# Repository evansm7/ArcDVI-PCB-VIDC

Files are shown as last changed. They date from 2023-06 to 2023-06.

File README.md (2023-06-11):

# ArcDVI VIDC push-on PCB

Kicad 6.0 PCB design for the ArcDVI soldered-VIDC push-on board:

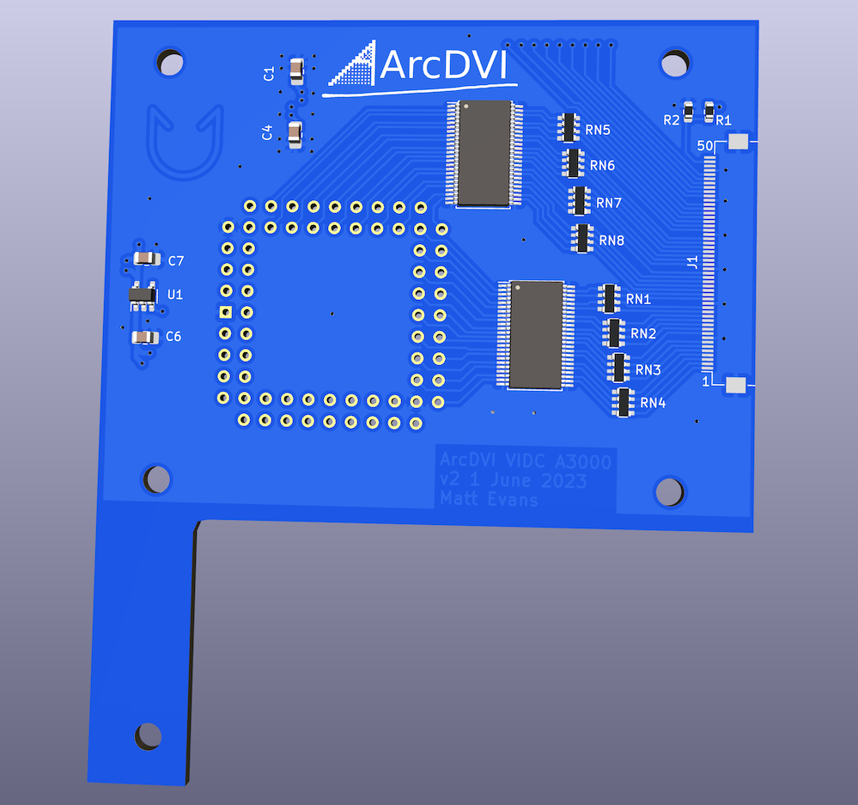
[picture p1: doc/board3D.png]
3D board


This board carries an upturned PTH PLCC68 which plugs onto a soldered VIDC from above.  This should fit an Acorn A3000, but hasn't been mechanically tested with the other soldered-VIDC machine, A5000.  The board exports the buffered signals over FFC to the ArcDVI main PCB.  Mechanically, the main PCB is designed to bolt on top of this board (with appropriate spacers) and fit underneath the floppy drive.

See <https://stardot.org.uk> for more info.

# License

ArcDVI is copyright 2023 Matt Evans.

This work is licensed under the Creative Commons Attribution-NonCommercial-ShareAlike 3.0 Unported License. To view a copy of this license, visit http://creativecommons.org/licenses/by-nc-sa/3.0/ or send a letter to Creative Commons, PO Box 1866, Mountain View, CA 94042, USA.

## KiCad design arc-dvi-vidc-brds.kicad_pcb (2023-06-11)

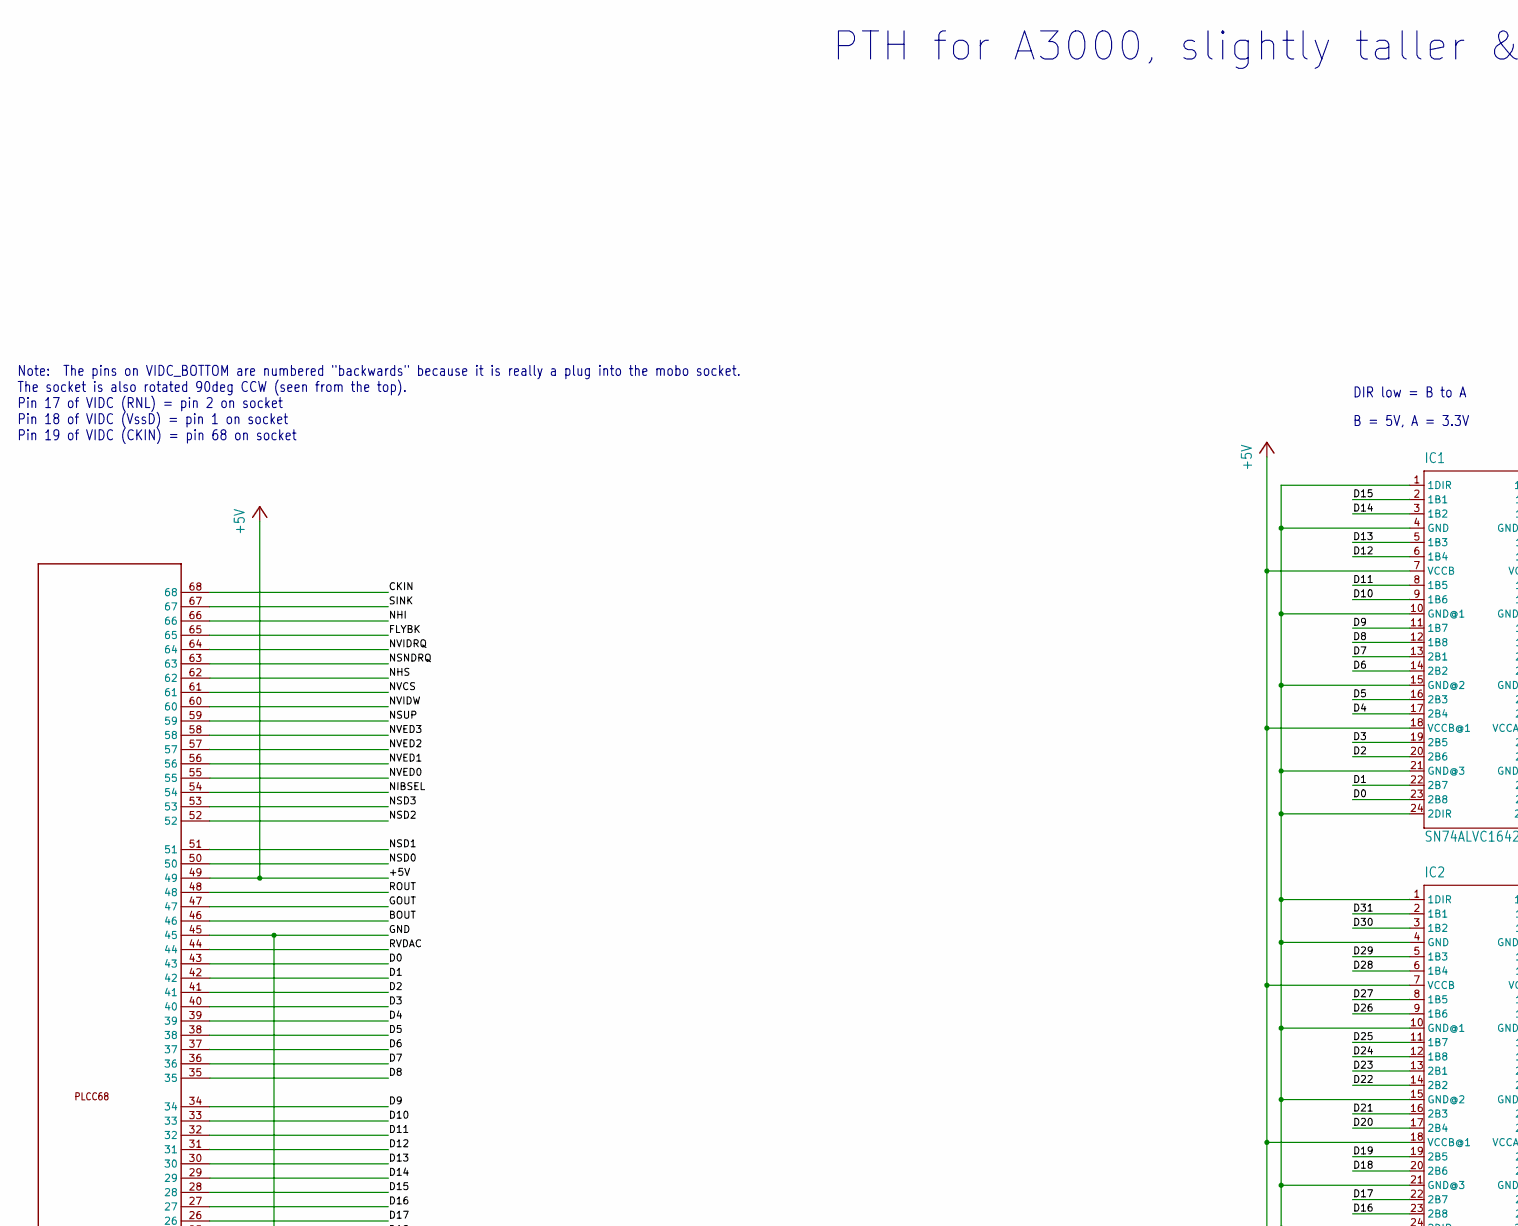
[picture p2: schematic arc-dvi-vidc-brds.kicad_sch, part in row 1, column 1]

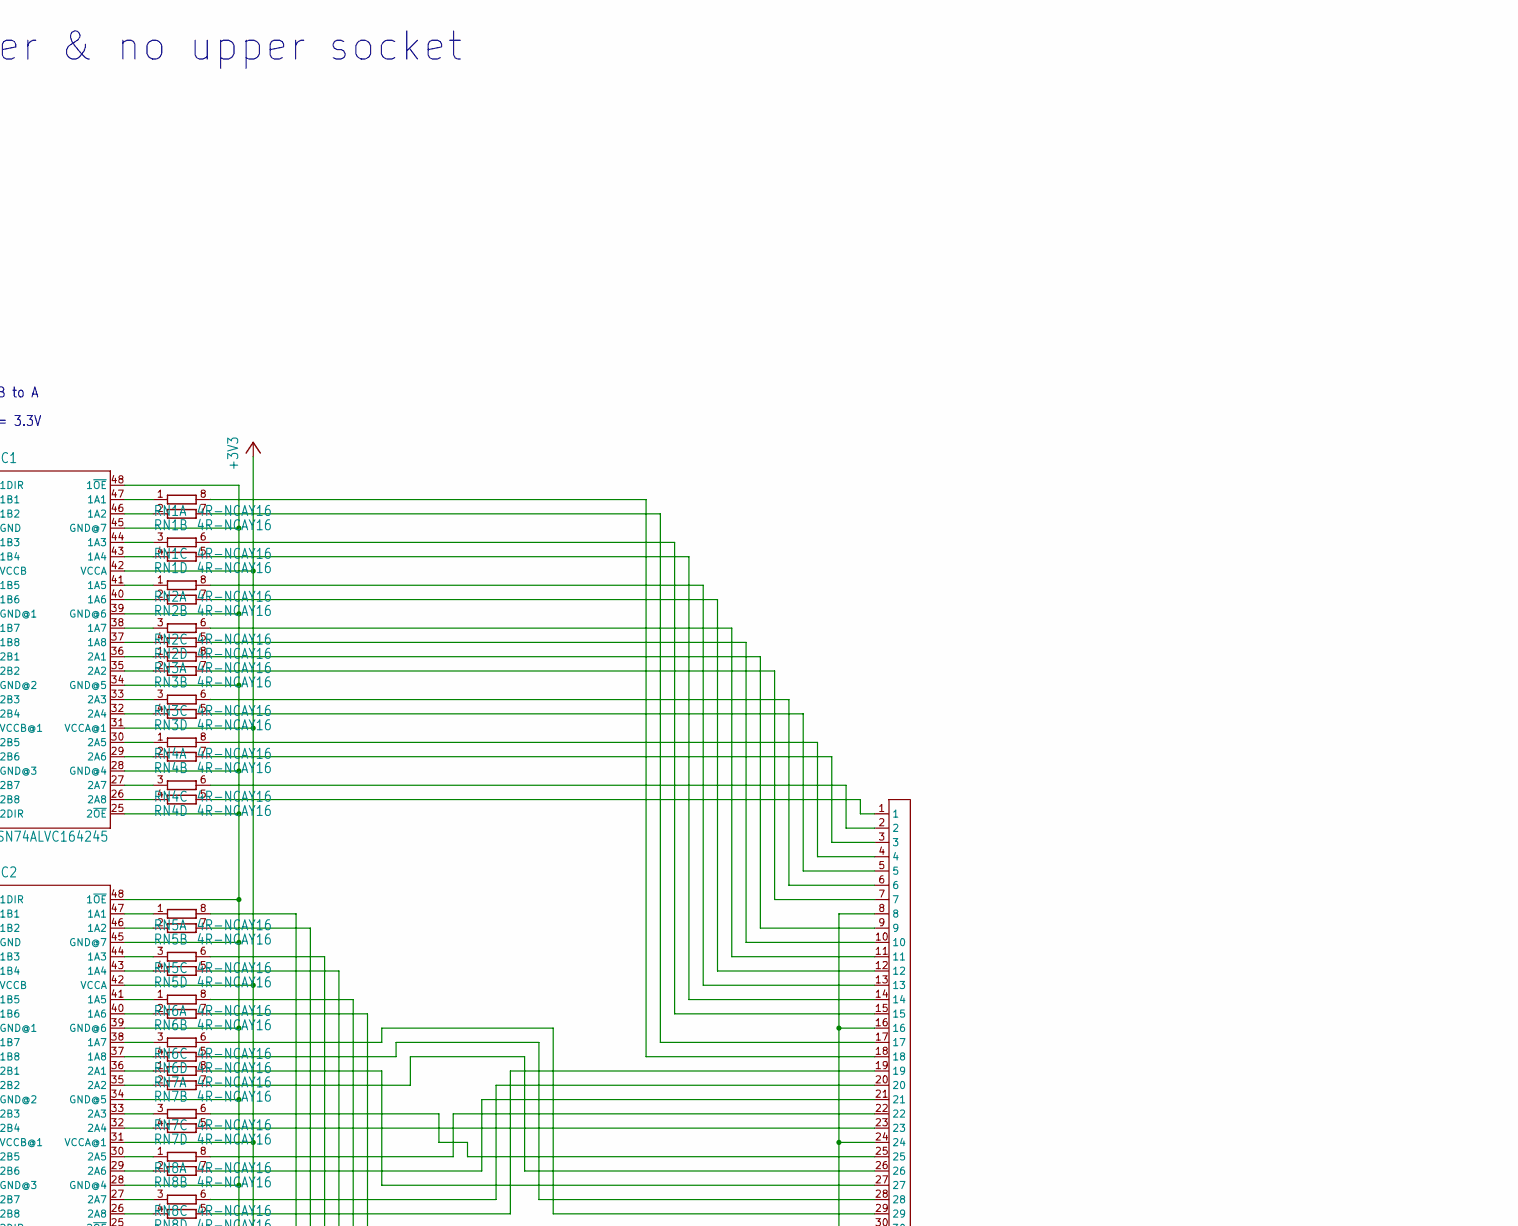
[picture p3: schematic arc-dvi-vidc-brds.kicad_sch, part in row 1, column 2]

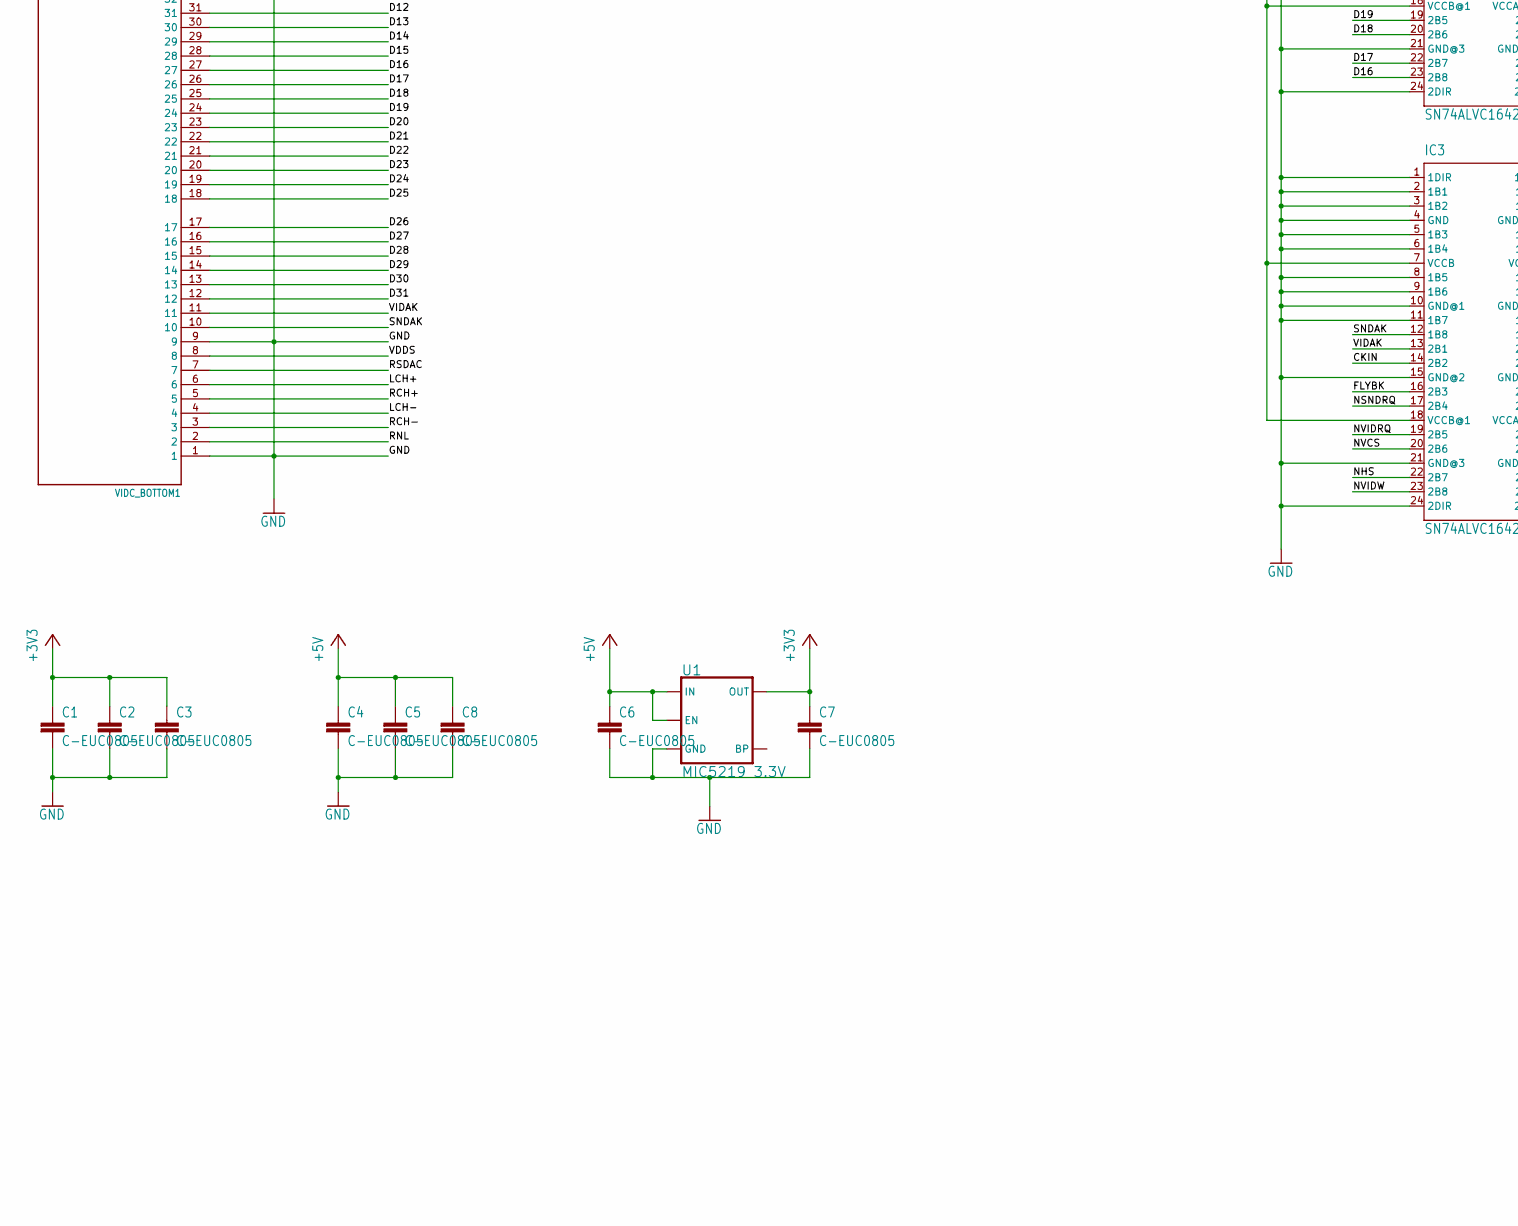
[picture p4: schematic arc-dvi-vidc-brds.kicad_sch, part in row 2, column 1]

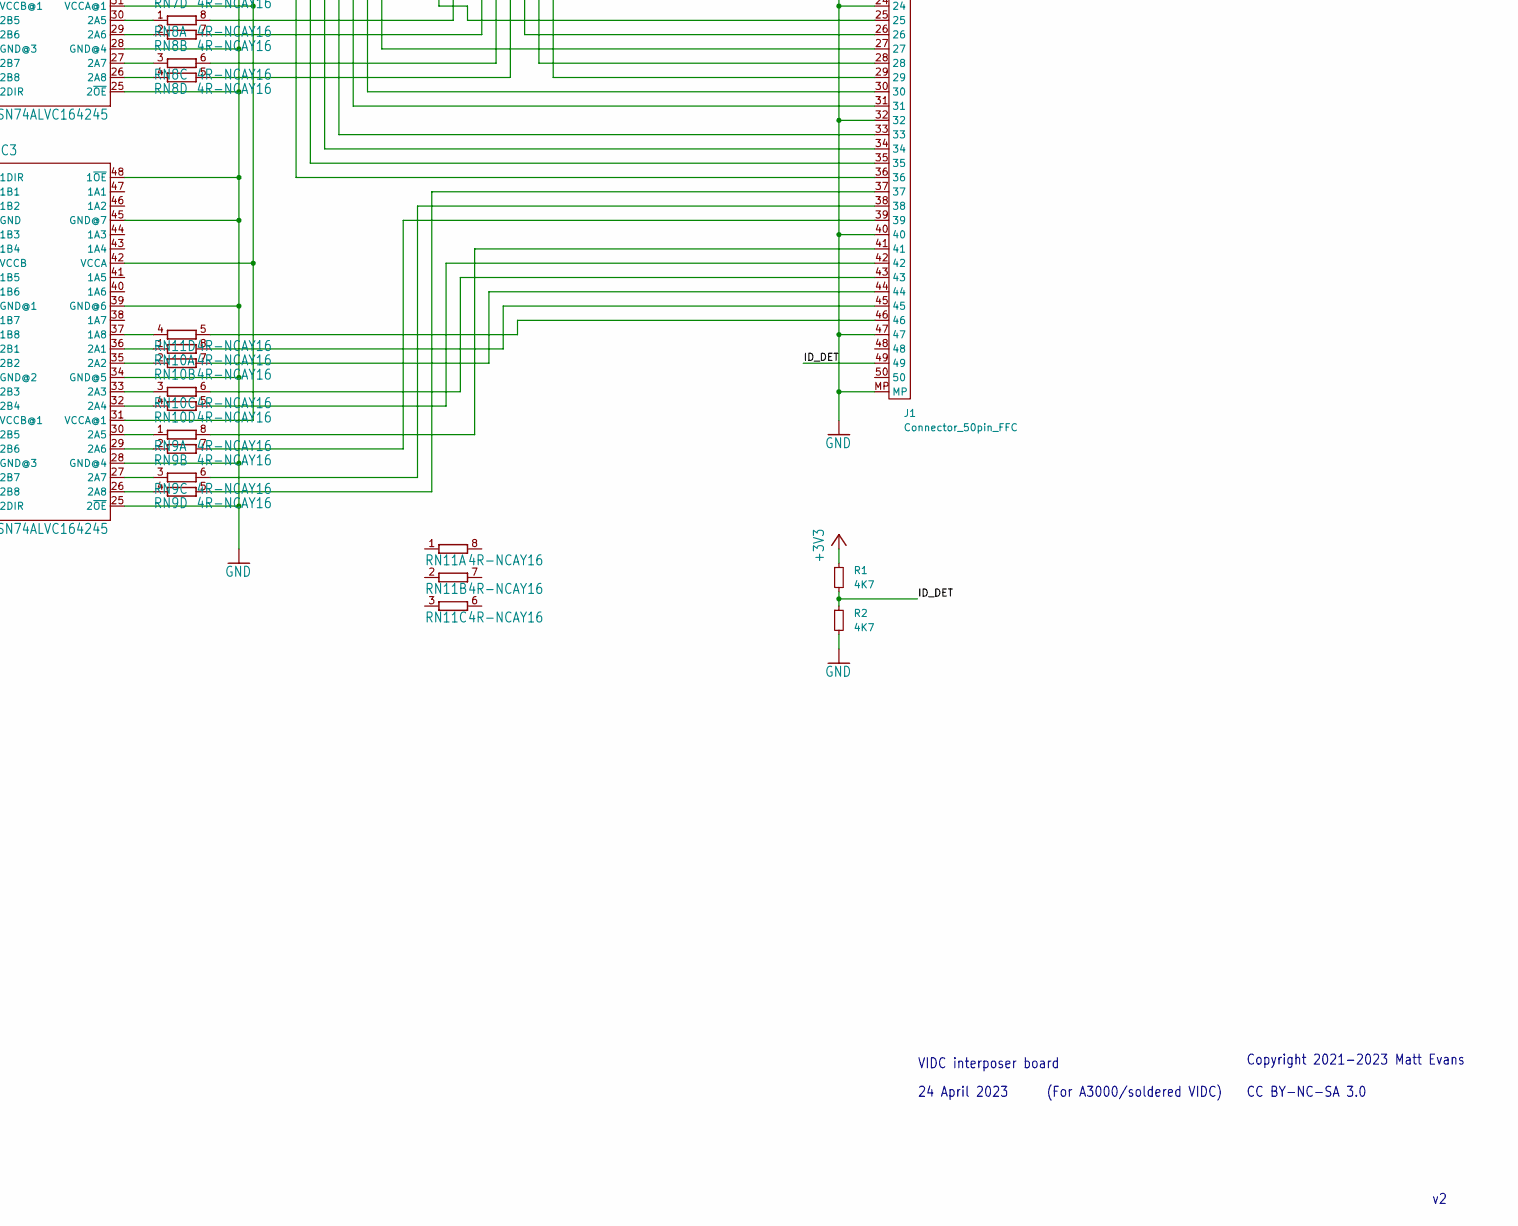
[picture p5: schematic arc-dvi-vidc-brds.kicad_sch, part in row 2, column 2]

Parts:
C1, C2, C3, C4, C5, C6, C7, C8: C-EUC0805; C_0805_2012Metric_Pad1.18x1.45mm_HandSolder
IC1, IC2, IC3: SN74ALVC164245; TSSOP-48_6.1x12.5mm_P0.5mm
J1: Connector_50pin_FFC; Hirose_FH12-50S-0.5SH_1x50-1MP_P0.50mm_Horizontal
R1, R2: 4K7; R_0603_1608Metric
RN1, RN2, RN3, RN4, RN5, RN6, RN7, RN8, RN9, RN10, RN11: 4R-NCAY16; R_Array_Convex_4x0603
U1: MIC5219 3.3V; SOT-23-5
VIDC_BOTTOM1: RAW_PLCC68PTH; PLCC-68_THT-Socket

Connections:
+3V3: C1.1, C2.1, C3.1, C7.1, IC1.31 (VCCA@1), IC1.42 (VCCA), IC2.31 (VCCA@1), IC2.42 (VCCA), IC3.31 (VCCA@1), IC3.42 (VCCA), R1.1, U1.5 (OUT)
+5V: C4.1, C5.1, C6.1, C8.1, IC1.7 (VCCB), IC1.18 (VCCB@1), IC2.7 (VCCB), IC2.18 (VCCB@1), IC3.7 (VCCB), IC3.18 (VCCB@1), U1.1 (IN), U1.3 (EN), VIDC_BOTTOM1.49
/BOUT: VIDC_BOTTOM1.46
/CKIN: IC3.14 (2B2), VIDC_BOTTOM1.68
/D0: IC1.23 (2B8), VIDC_BOTTOM1.43
/D1: IC1.22 (2B7), VIDC_BOTTOM1.42
/D2: IC1.20 (2B6), VIDC_BOTTOM1.41
/D3: IC1.19 (2B5), VIDC_BOTTOM1.40
/D4: IC1.17 (2B4), VIDC_BOTTOM1.39
/D5: IC1.16 (2B3), VIDC_BOTTOM1.38
/D6: IC1.14 (2B2), VIDC_BOTTOM1.37
/D7: IC1.13 (2B1), VIDC_BOTTOM1.36
/D8: IC1.12 (1B8), VIDC_BOTTOM1.35
/D9: IC1.11 (1B7), VIDC_BOTTOM1.34
/D10: IC1.9 (1B6), VIDC_BOTTOM1.33
/D11: IC1.8 (1B5), VIDC_BOTTOM1.32
/D12: IC1.6 (1B4), VIDC_BOTTOM1.31
/D13: IC1.5 (1B3), VIDC_BOTTOM1.30
/D14: IC1.3 (1B2), VIDC_BOTTOM1.29
/D15: IC1.2 (1B1), VIDC_BOTTOM1.28
/D16: IC2.23 (2B8), VIDC_BOTTOM1.27
/D17: IC2.22 (2B7), VIDC_BOTTOM1.26
/D18: IC2.20 (2B6), VIDC_BOTTOM1.25
/D19: IC2.19 (2B5), VIDC_BOTTOM1.24
/D20: IC2.17 (2B4), VIDC_BOTTOM1.23
/D21: IC2.16 (2B3), VIDC_BOTTOM1.22
/D22: IC2.14 (2B2), VIDC_BOTTOM1.21
/D23: IC2.13 (2B1), VIDC_BOTTOM1.20
/D24: IC2.12 (1B8), VIDC_BOTTOM1.19
/D25: IC2.11 (1B7), VIDC_BOTTOM1.18
/D26: IC2.9 (1B6), VIDC_BOTTOM1.17
/D27: IC2.8 (1B5), VIDC_BOTTOM1.16
/D28: IC2.6 (1B4), VIDC_BOTTOM1.15
/D29: IC2.5 (1B3), VIDC_BOTTOM1.14
/D30: IC2.3 (1B2), VIDC_BOTTOM1.13
/D31: IC2.2 (1B1), VIDC_BOTTOM1.12
/FLYBK: IC3.16 (2B3), VIDC_BOTTOM1.65
/GOUT: VIDC_BOTTOM1.47
/ID_DET: J1.49, R1.2, R2.1
/LCH+: VIDC_BOTTOM1.6
/LCH-: VIDC_BOTTOM1.4
/NHI: VIDC_BOTTOM1.66
/NHS: IC3.22 (2B7), VIDC_BOTTOM1.62
/NIBSEL: VIDC_BOTTOM1.54
/NSD0: VIDC_BOTTOM1.50
/NSD1: VIDC_BOTTOM1.51
/NSD2: VIDC_BOTTOM1.52
/NSD3: VIDC_BOTTOM1.53
/NSNDRQ: IC3.17 (2B4), VIDC_BOTTOM1.63
/NSUP: VIDC_BOTTOM1.59
/NVCS: IC3.20 (2B6), VIDC_BOTTOM1.61
/NVED0: VIDC_BOTTOM1.55
/NVED1: VIDC_BOTTOM1.56
/NVED2: VIDC_BOTTOM1.57
/NVED3: VIDC_BOTTOM1.58
/NVIDRQ: IC3.19 (2B5), VIDC_BOTTOM1.64
/NVIDW: IC3.23 (2B8), VIDC_BOTTOM1.60
/RCH+: VIDC_BOTTOM1.5
/RCH-: VIDC_BOTTOM1.3
/RNL: VIDC_BOTTOM1.2
/ROUT: VIDC_BOTTOM1.48
/RSDAC: VIDC_BOTTOM1.7
/RVDAC: VIDC_BOTTOM1.44
/SINK: VIDC_BOTTOM1.67
/SNDAK: IC3.12 (1B8), VIDC_BOTTOM1.10
/VDDS: VIDC_BOTTOM1.8
/VIDAK: IC3.13 (2B1), VIDC_BOTTOM1.11
GND: C1.2, C2.2, C3.2, C4.2, C5.2, C6.2, C7.2, C8.2, IC1.1 (1DIR), IC1.4 (GND), IC1.10 (GND@1), IC1.15 (GND@2), IC1.21 (GND@3), IC1.24 (2DIR), IC1.25 (2~OE), IC1.28 (GND@4), IC1.34 (GND@5), IC1.39 (GND@6), IC1.45 (GND@7), IC1.48 (1~OE), IC2.1 (1DIR), IC2.4 (GND), IC2.10 (GND@1), IC2.15 (GND@2), IC2.21 (GND@3), IC2.24 (2DIR), IC2.25 (2~OE), IC2.28 (GND@4), IC2.34 (GND@5), IC2.39 (GND@6), IC2.45 (GND@7), IC2.48 (1~OE), IC3.1 (1DIR), IC3.2 (1B1), IC3.3 (1B2), IC3.4 (GND), IC3.5 (1B3), IC3.6 (1B4), IC3.8 (1B5), IC3.9 (1B6), IC3.10 (GND@1), IC3.11 (1B7), IC3.15 (GND@2), IC3.21 (GND@3), IC3.24 (2DIR), IC3.25 (2~OE), IC3.28 (GND@4), IC3.34 (GND@5), IC3.39 (GND@6), IC3.45 (GND@7), IC3.48 (1~OE), J1.8, J1.16, J1.24, J1.32, J1.40, J1.47, J1.MP, R2.2, U1.2 (GND), VIDC_BOTTOM1.1, VIDC_BOTTOM1.9, VIDC_BOTTOM1.45
unnamed: IC1.26 (2A8), RN4.4 (1)
unnamed: IC1.27 (2A7), RN4.3 (1)
unnamed: IC1.29 (2A6), RN4.2 (1)
unnamed: IC1.30 (2A5), RN4.1
unnamed: IC1.32 (2A4), RN3.4 (1)
unnamed: IC1.33 (2A3), RN3.3 (1)
unnamed: IC1.35 (2A2), RN3.2 (1)
unnamed: IC1.36 (2A1), RN3.1
unnamed: IC1.37 (1A8), RN2.4 (1)
unnamed: IC1.38 (1A7), RN2.3 (1)
unnamed: IC1.40 (1A6), RN2.2 (1)
unnamed: IC1.41 (1A5), RN2.1
unnamed: IC1.43 (1A4), RN1.4 (1)
unnamed: IC1.44 (1A3), RN1.3 (1)
unnamed: IC1.46 (1A2), RN1.2 (1)
unnamed: IC1.47 (1A1), RN1.1
unnamed: IC2.26 (2A8), RN8.4 (1)
unnamed: IC2.27 (2A7), RN8.3 (1)
unnamed: IC2.29 (2A6), RN8.2 (1)
unnamed: IC2.30 (2A5), RN8.1
unnamed: IC2.32 (2A4), RN7.4 (1)
unnamed: IC2.33 (2A3), RN7.3 (1)
unnamed: IC2.35 (2A2), RN7.2 (1)
unnamed: IC2.36 (2A1), RN7.1
unnamed: IC2.37 (1A8), RN6.4 (1)
unnamed: IC2.38 (1A7), RN6.3 (1)
unnamed: IC2.40 (1A6), RN6.2 (1)
unnamed: IC2.41 (1A5), RN6.1
unnamed: IC2.43 (1A4), RN5.4 (1)
unnamed: IC2.44 (1A3), RN5.3 (1)
unnamed: IC2.46 (1A2), RN5.2 (1)
unnamed: IC2.47 (1A1), RN5.1
unnamed: IC3.26 (2A8), RN9.4 (1)
unnamed: IC3.27 (2A7), RN9.3 (1)
unnamed: IC3.29 (2A6), RN9.2 (1)
unnamed: IC3.30 (2A5), RN9.1
unnamed: IC3.32 (2A4), RN10.4 (1)
unnamed: IC3.33 (2A3), RN10.3 (1)
unnamed: IC3.35 (2A2), RN10.2 (1)
unnamed: IC3.36 (2A1), RN10.1
unnamed: IC3.37 (1A8), RN11.4 (1)
unnamed: J1.1, RN4.5 (2)
unnamed: J1.2, RN4.6 (2)
unnamed: J1.3, RN4.7 (2)
unnamed: J1.4, RN4.8 (2)
unnamed: J1.5, RN3.5 (2)
unnamed: J1.6, RN3.6 (2)
unnamed: J1.7, RN3.7 (2)
unnamed: J1.9, RN3.8 (2)
unnamed: J1.10, RN2.5 (2)
unnamed: J1.11, RN2.6 (2)
unnamed: J1.12, RN2.7 (2)
unnamed: J1.13, RN2.8 (2)
unnamed: J1.14, RN1.5 (2)
unnamed: J1.15, RN1.6 (2)
unnamed: J1.17, RN1.7 (2)
unnamed: J1.18, RN1.8 (2)
unnamed: J1.19, RN8.5 (2)
unnamed: J1.20, RN8.6 (2)
unnamed: J1.21, RN8.7 (2)
unnamed: J1.22, RN8.8 (2)
unnamed: J1.23, RN7.5 (2)
unnamed: J1.25, RN7.6 (2)
unnamed: J1.26, RN7.7 (2)
unnamed: J1.27, RN7.8 (2)
unnamed: J1.28, RN6.5 (2)
unnamed: J1.29, RN6.6 (2)
unnamed: J1.30, RN6.7 (2)
unnamed: J1.31, RN6.8 (2)
unnamed: J1.33, RN5.5 (2)
unnamed: J1.34, RN5.6 (2)
unnamed: J1.35, RN5.7 (2)
unnamed: J1.36, RN5.8 (2)
unnamed: J1.37, RN9.5 (2)
unnamed: J1.38, RN9.6 (2)
unnamed: J1.39, RN9.7 (2)
unnamed: J1.41, RN9.8 (2)
unnamed: J1.42, RN10.5 (2)
unnamed: J1.43, RN10.6 (2)
unnamed: J1.44, RN10.7 (2)
unnamed: J1.45, RN10.8 (2)
unnamed: J1.46, RN11.5 (2)

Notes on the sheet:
VIDC interposer board
(For A3000/soldered VIDC)
DIR low = B to A
PTH for A3000, slightly taller & no upper socket~{}
24 April 2023
B = 5V, A = 3.3V
Copyright 2021-2023 Matt Evans CC BY-NC-SA 3.0
Note: The pins on VIDC_BOTTOM are numbered "backwards" because it is really a plug into the mobo socket. The socket is also rotated 90deg CCW (seen from the top). Pin 17 of VIDC (RNL) = pin 2 on socket Pin 18 of VIDC (VssD) = pin 1 on socket Pin 19 of VIDC (CKIN) = pin 68 on socket

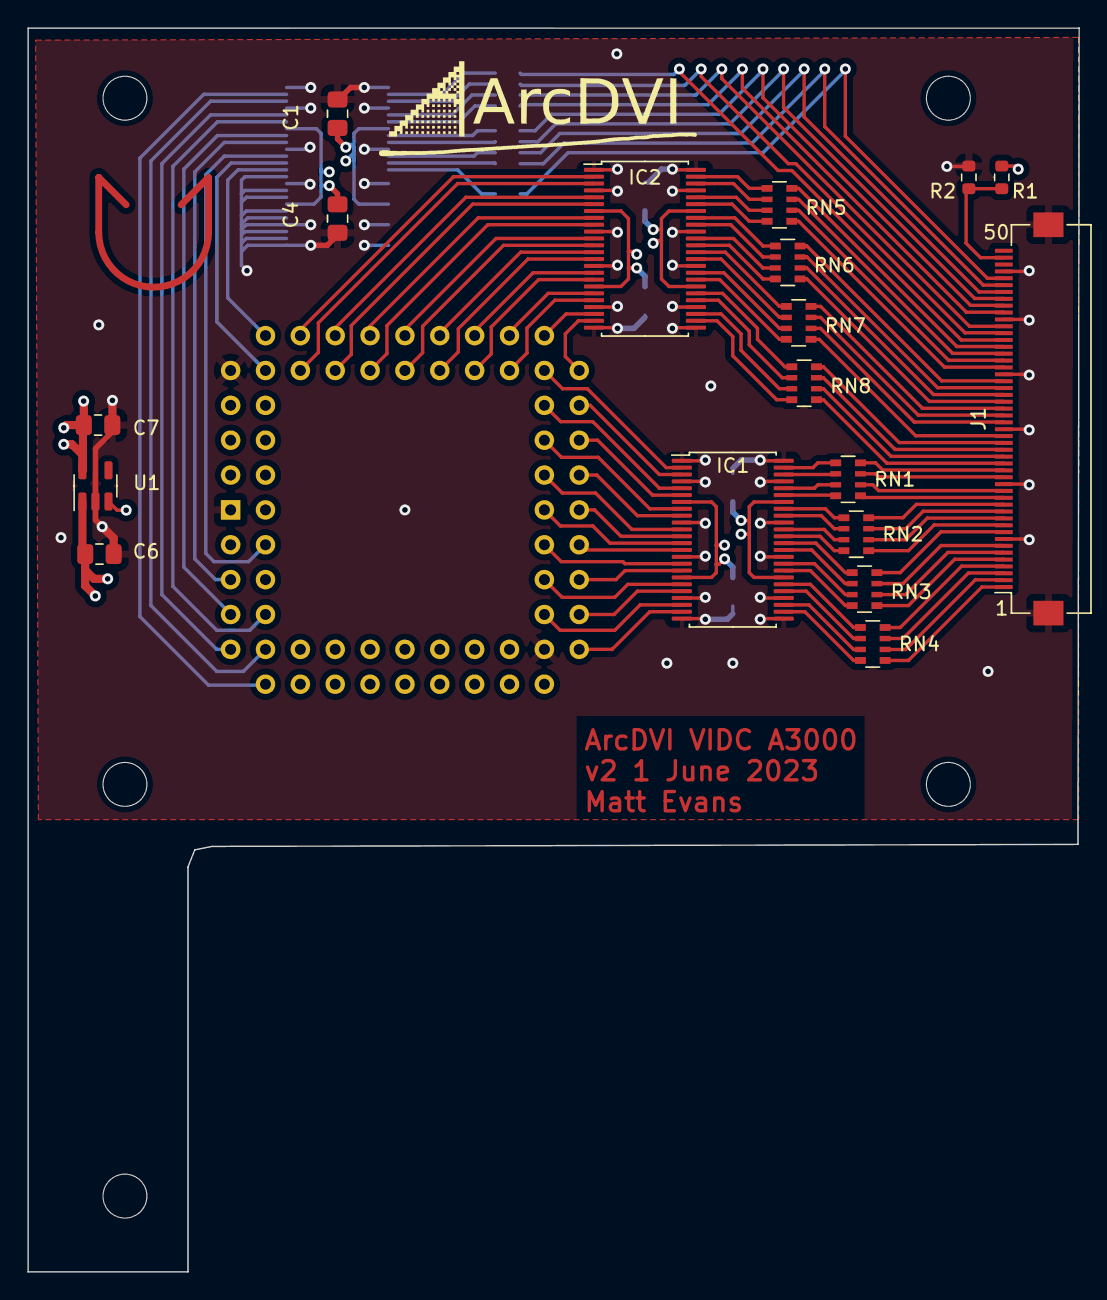
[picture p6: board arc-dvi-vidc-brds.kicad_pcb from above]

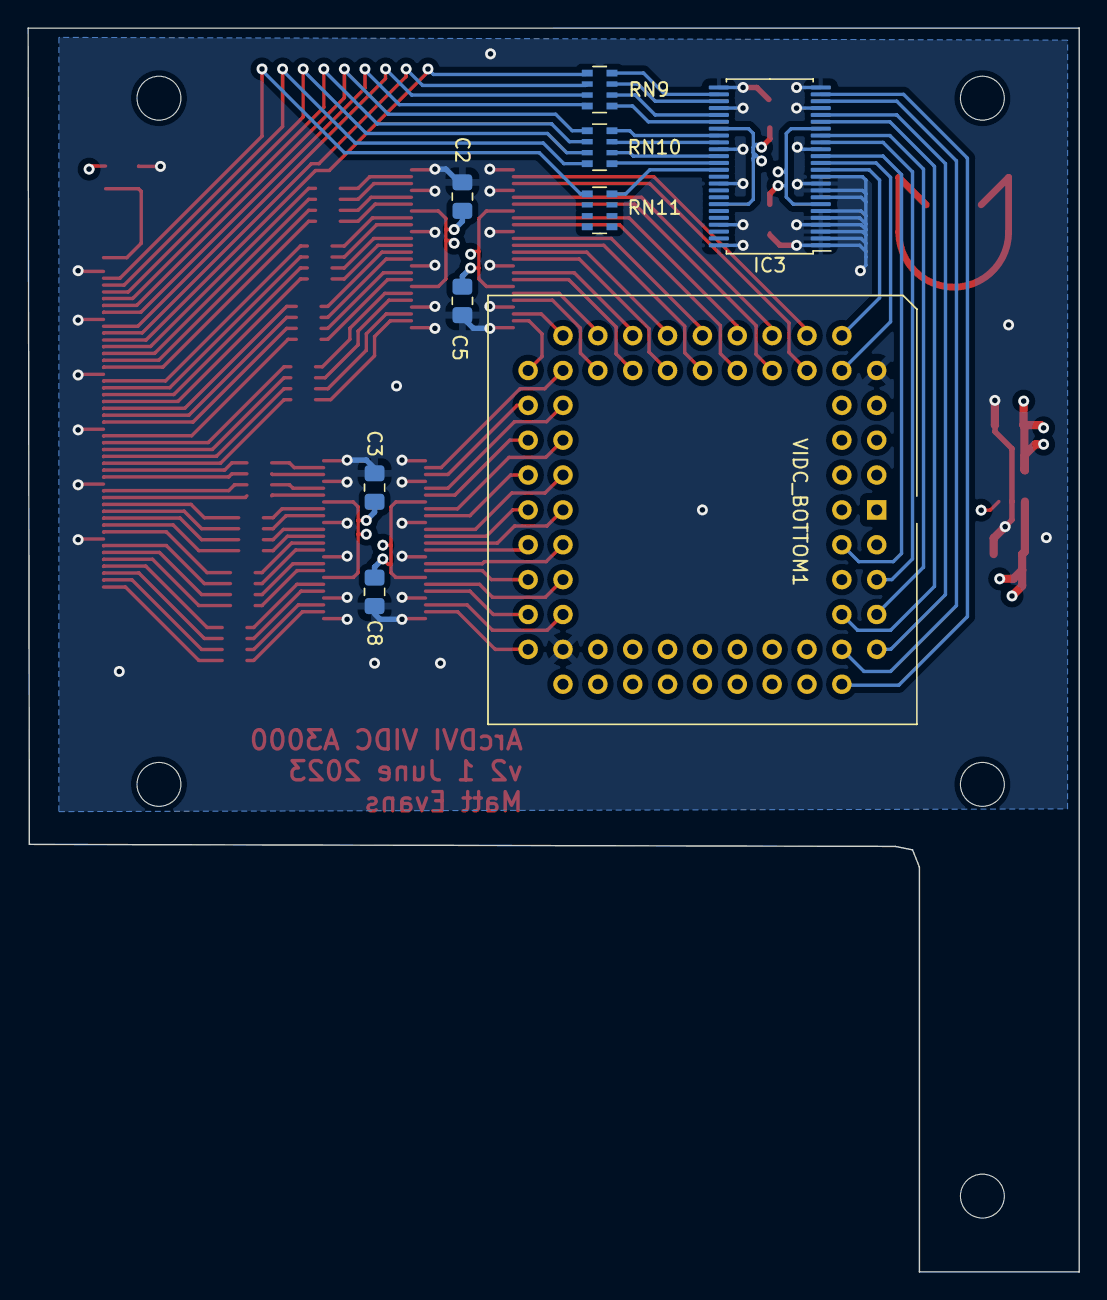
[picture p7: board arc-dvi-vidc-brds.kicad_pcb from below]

Board: 4 copper layers, 76.6 x 90.6 mm, 27 parts (9 on the bottom side), 127 nets.

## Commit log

2023-03-09 Board imported from Eagle, rerouted
    Now using FFC-50
    [arc-dvi-vidc-brds.kicad_pcb, arc-dvi-vidc-brds.kicad_sch]
2023-04-24 Pretty much finished
    Not DRC'd though, FIXME. Routed, with dimensions measured from
    A3000/FDD spacing etc. Includes extra 80mm holes to mount the
    podule board under FDD too.
    [arc-dvi-vidc-brds.kicad_pcb, arc-dvi-vidc-brds.kicad_sch]
2023-05-07 DRC clean
    [arc-dvi-vidc-brds.kicad_pcb]
2023-06-11 Tweaks to cap positions, power planes
    In good shape now, a few minor tweaks to go
    [arc-dvi-vidc-brds.kicad_pcb]
2023-06-11 Add logo
    [arc-dvi-vidc-brds.kicad_pcb]
2023-06-11 Moved holes to 60mm centers
    [arc-dvi-vidc-brds.kicad_pcb]
2023-06-11 Update date
    [arc-dvi-vidc-brds.kicad_pcb]
2023-06-11 Move regulator, move holes
    Reg move now makes PLCC socket centre bare, ideal for mechanical pressure point.
    Holes now mean main ArcDVI board lines up preciselyish.
    [arc-dvi-vidc-brds.kicad_pcb]
2023-06-11 Add README, licence
    [arc-dvi-vidc-brds.kicad_pcb, arc-dvi-vidc-brds.kicad_sch]
